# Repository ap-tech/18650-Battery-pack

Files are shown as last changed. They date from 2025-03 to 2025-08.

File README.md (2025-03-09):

# 18650-Battery-pack
This is a repository for making 18650 Battery packs. I will be making 3cell, 4cell, and 6cell. All packs will have inbuilt battery balancer from AliExpress I will also be looking at charging with just an off the shelf 24v power supply or transformer. The reason for this is so that you don't need to use "hard to come by" hobby modle chargers

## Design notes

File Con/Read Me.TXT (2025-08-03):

README: Handheld Device Schematic (KiCad)
Overview

This repository contains the KiCad schematic for a versatile handheld device. The design focuses on providing a robust foundation for custom projects, integrating a microcontroller with a power management solution that supports charging from a 24V transformer. This schematic is intended to be a starting point for hobbyists, students, and engineers looking to quickly prototype and build their own portable electronic devices.
Features

 Microcontroller Integration: Designed to easily accommodate a SAMD21 microcontroller with necessary power and peripheral connections.

3-Cell 18650 Battery Support: Includes provisions for a 3-cell 18650 battery pack, providing portable power for the device.

24V Charging Capability: Includes a power management circuit capable of safely stepping down and regulating a 24V DC input for charging the 3-cell 18650 battery pack and powering the device operation.

Modular Design: The schematic is organized into logical blocks, making it easy to understand, modify, and adapt for various applications.

KiCad Format: Provided in KiCad's native format, ensuring full compatibility for editing, simulation, and PCB layout generation.

How to Use This Schematic

To utilize this schematic for your own projects, follow these steps:

Review and Understand: Familiarize yourself with the different sections of the schematic, including the microcontroller section, power management, and any peripheral interfaces.

Customize:

Microcontroller: Adapt the pin assignments and peripheral connections to match your SAMD21 microcontroller.

Peripherals: Add or remove components for specific sensors, displays, communication modules, or other functionalities your handheld device requires.

Create PCB Layout: Once you are satisfied with the schematic, use KiCad's PCB editor to design your custom printed circuit board based on this schematic. Ensure proper component footprints and routing for optimal performance.

Important Considerations

Component Selection: While the schematic provides placeholders, ensure you select appropriate components with the correct voltage ratings, current capabilities, and package types for your application, especially those related to the 24V input and 3-cell 18650 battery pack.

Battery Management: The 24V charging circuit is designed for basic power input to charge a 3-cell 18650 battery pack. For proper and safe charging of Li-Ion batteries like 18650s, it is crucial to integrate a dedicated Battery Management System (BMS) IC. This BMS should handle aspects like cell balancing, over-charge protection, over-discharge protection, and over-current protection to ensure battery longevity and safety. The schematic provides the power path, but a comprehensive BMS is highly recommended for the battery pack.

Safety: Always exercise caution when working with electrical circuits, especially those involving higher voltages and Li-Ion batteries. Double-check your connections and component ratings. Improper handling of Li-Ion batteries can be dangerous.

Testing: Thoroughly test your assembled board, starting with power supply checks, before connecting sensitive components or full functionality.

Contributing

Feel free to fork this repository, make improvements, or suggest changes. Your contributions are welcome!
License

This project is open-source and released under the MIT License.

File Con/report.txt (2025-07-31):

Info: Total warnings: 0, errors: 0.
Info: Processing symbol 'U1:Package_QFP:TQFP-48_7x7mm_P0.5mm'.
Added U1 (footprint 'Package_QFP:TQFP-48_7x7mm_P0.5mm').
Changed REF** reference designator to U1.
Changed U1 value from TQFP-48_7x7mm_P0.5mm to ATSAMD21G15B-A.
Updated U1 symbol association from  to /875e85b6-29ea-47d7-8ef3-6b790c67f0cd.
Updated U1 fields.
Updated U1 sheetname to '/'.
Updated U1 sheetfile to 'Con.kicad_sch'.
Updated U1 footprint filters to 'TQFP*7x7mm*P0.5mm*'.
Add net unconnected-(U1-PA30-Pad45).
Connected U1 pin 45 to unconnected-(U1-PA30-Pad45).
Add net unconnected-(U1-PA13-Pad22).
Connected U1 pin 22 to unconnected-(U1-PA13-Pad22).
Add net unconnected-(U1-PA08-Pad13).
Connected U1 pin 13 to unconnected-(U1-PA08-Pad13).
Add net unconnected-(U1-PB10-Pad19).
Connected U1 pin 19 to unconnected-(U1-PB10-Pad19).
Add net unconnected-(U1-PA19-Pad28).
Connected U1 pin 28 to unconnected-(U1-PA19-Pad28).
Add net unconnected-(U1-VDDANA-Pad6).
Connected U1 pin 6 to unconnected-(U1-VDDANA-Pad6).
Add net unconnected-(U1-PA23-Pad32).
Connected U1 pin 32 to unconnected-(U1-PA23-Pad32).
Add net unconnected-(U1-PA12-Pad21).
Connected U1 pin 21 to unconnected-(U1-PA12-Pad21).
Add net unconnected-(U1-PA22-Pad31).
Connected U1 pin 31 to unconnected-(U1-PA22-Pad31).
Add net unconnected-(U1-VDDIO-Pad17).
Connected U1 pin 17 to unconnected-(U1-VDDIO-Pad17).
Add net Net-(U1-GND-Pad18).
Connected U1 pin 18 to Net-(U1-GND-Pad18).
Add net unconnected-(U1-PB22-Pad37).
Connected U1 pin 37 to unconnected-(U1-PB22-Pad37).
Add net unconnected-(U1-PA15-Pad24).
Connected U1 pin 24 to unconnected-(U1-PA15-Pad24).
Add net unconnected-(U1-PA21-Pad30).
Connected U1 pin 30 to unconnected-(U1-PA21-Pad30).
Add net unconnected-(U1-PB02-Pad47).
Connected U1 pin 47 to unconnected-(U1-PB02-Pad47).
Add net unconnected-(U1-PA09-Pad14).
Connected U1 pin 14 to unconnected-(U1-PA09-Pad14).
Add net unconnected-(U1-PA28-Pad41).
Connected U1 pin 41 to unconnected-(U1-PA28-Pad41).
Add net unconnected-(U1-PA10-Pad15).
Connected U1 pin 15 to unconnected-(U1-PA10-Pad15).
Add net unconnected-(U1-PA31-Pad46).
Connected U1 pin 46 to unconnected-(U1-PA31-Pad46).
Add net unconnected-(U1-PA24-Pad33).
Connected U1 pin 33 to unconnected-(U1-PA24-Pad33).
Add net unconnected-(U1-PB23-Pad38).
Connected U1 pin 38 to unconnected-(U1-PB23-Pad38).
Add net unconnected-(U1-PA04-Pad9).
Connected U1 pin 9 to unconnected-(U1-PA04-Pad9).
Connected U1 pin 7 to unconnected-(U1-PB08-Pad7).
Add net unconnected-(U1-PA03-Pad4).
Connected U1 pin 4 to unconnected-(U1-PA03-Pad4).
Connected U1 pin 42 to Net-(U1-GND-Pad18).
Add net unconnected-(U1-PA17-Pad26).
Connected U1 pin 26 to unconnected-(U1-PA17-Pad26).
Add net unconnected-(U1-PB11-Pad20).
Connected U1 pin 20 to unconnected-(U1-PB11-Pad20).
Add net unconnected-(U1-VDDIO-Pad36).
Connected U1 pin 36 to unconnected-(U1-VDDIO-Pad36).
Add net unconnected-(U1-PA27-Pad39).
Connected U1 pin 39 to unconnected-(U1-PA27-Pad39).
Add net unconnected-(U1-GNDANA-Pad5).
Connected U1 pin 5 to unconnected-(U1-GNDANA-Pad5).
Connected U1 pin 35 to Net-(U1-GND-Pad18).
Add net unconnected-(U1-PA02-Pad3).
Connected U1 pin 3 to unconnected-(U1-PA02-Pad3).
Add net unconnected-(U1-PA11-Pad16).
Connected U1 pin 16 to unconnected-(U1-PA11-Pad16).
Add net unconnected-(U1-~{RESET}-Pad40).
Connected U1 pin 40 to unconnected-(U1-~{RESET}-Pad40).
Add net unconnected-(U1-PA00-Pad1).
Connected U1 pin 1 to unconnected-(U1-PA00-Pad1).
Add net unconnected-(U1-PB03-Pad48).
Connected U1 pin 48 to unconnected-(U1-PB03-Pad48).
Add net unconnected-(U1-VDDCORE-Pad43).
Connected U1 pin 43 to unconnected-(U1-VDDCORE-Pad43).
Add net unconnected-(U1-PA25-Pad34).
Connected U1 pin 34 to unconnected-(U1-PA25-Pad34).
Add net unconnected-(U1-PA05-Pad10).
Connected U1 pin 10 to unconnected-(U1-PA05-Pad10).
Add net unconnected-(U1-PA06-Pad11).
Connected U1 pin 11 to unconnected-(U1-PA06-Pad11).
Add net unconnected-(U1-VDDIN-Pad44).
Connected U1 pin 44 to unconnected-(U1-VDDIN-Pad44).
Add net unconnected-(U1-PB09-Pad8).
Connected U1 pin 8 to unconnected-(U1-PB09-Pad8).
Add net unconnected-(U1-PA14-Pad23).
Connected U1 pin 23 to unconnected-(U1-PA14-Pad23).
Add net unconnected-(U1-PA18-Pad27).
Connected U1 pin 27 to unconnected-(U1-PA18-Pad27).
Add net unconnected-(U1-PA07-Pad12).
Connected U1 pin 12 to unconnected-(U1-PA07-Pad12).
Add net unconnected-(U1-PA16-Pad25).
Connected U1 pin 25 to unconnected-(U1-PA16-Pad25).
Add net unconnected-(U1-PA01-Pad2).
Connected U1 pin 2 to unconnected-(U1-PA01-Pad2).
Add net unconnected-(U1-PA20-Pad29).
Connected U1 pin 29 to unconnected-(U1-PA20-Pad29).

Add net unconnected-(U1-PB08-Pad7).

Info: Total warnings: 0, errors: 0.

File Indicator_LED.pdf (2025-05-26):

# Indicator RGB LED

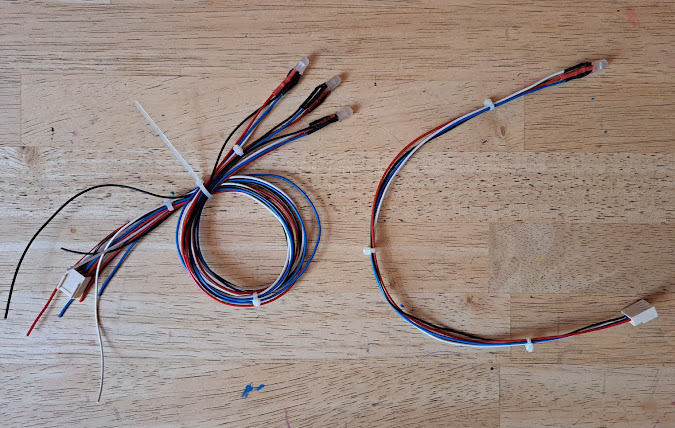
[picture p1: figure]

Indicator LEDs mainly to show battery power level on my robots. Originally I was thinking about using them on my remote controllers as well but then decided to use OLED displays for that. The heart and soul of the indicator is the WS2812 5mm LED. preferably the diffused or milky type. I don’t like the clear type since you can see the individual LEDs in the package instead of just the single output colour. On the other side of the wire harness is a 4 pin female 2510-AW-2.5 connector. In some of them (as can be seen in the left of the pic) I did not attach a connector incase there was to much wire for the application. in that case you just cut the length of wire that you need and then attach the connector. integrated in the assembly is a 470 ohm resistor it’s covered with a red heat shrink and is on the VDD or the power pin. The input power for this device is 5 voltes and the data sheet says to put a 100 ohm resistor on the power pin but I chose a 470 ohm one. I think having the power resistor integrated like this will save board space on the charging board. I don’t know the wire’s gauge but it is the thinest wire I could get from my local supplier. The colours used are red, Blue, White, and Black. also I used the smallest cable ties I have to keep everything together as can be seen on the right in the pic.

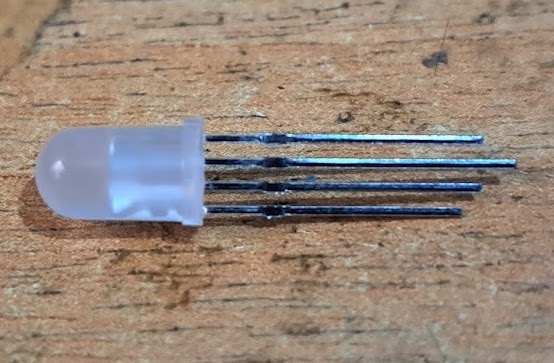
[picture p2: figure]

This is the WS2812 5mm LED. I got a hundred of them from AliExpress for very cheap.

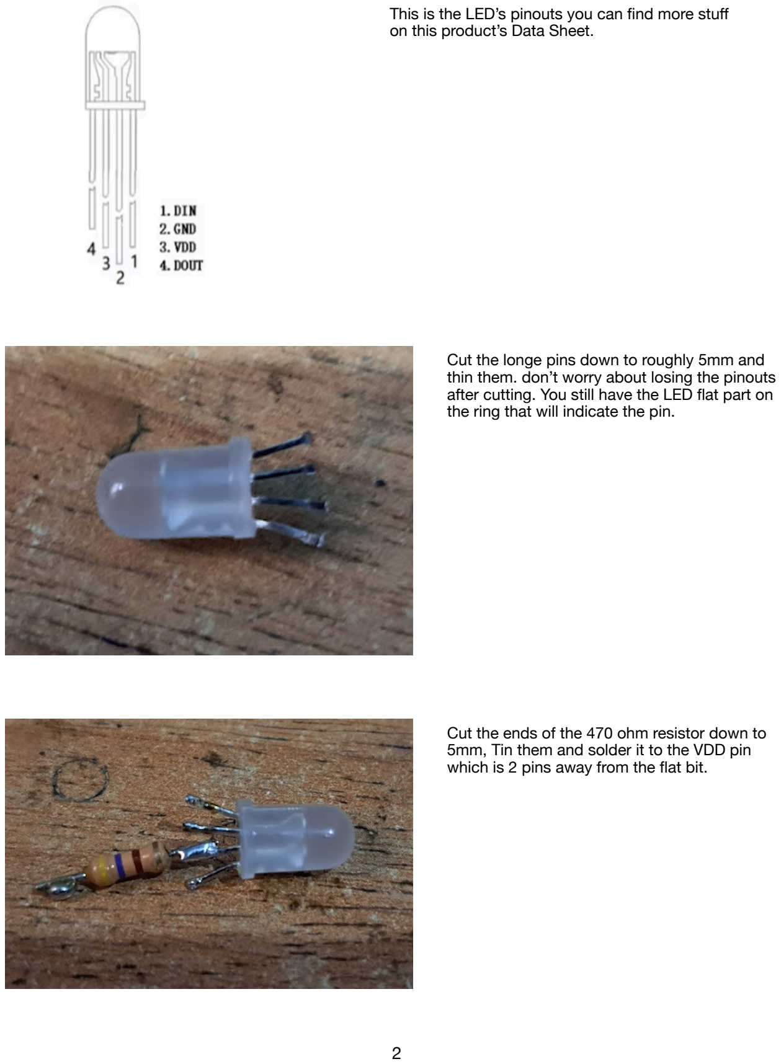
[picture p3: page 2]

This is the LED’s pinouts you can find more stuff on this product’s Data Sheet.

Cut the longe pins down to roughly 5mm and thin them. don’t worry about losing the pinouts after cutting. You still have the LED flat part on the ring that will indicate the pin.

Cut the ends of the 470 ohm resistor down to 5mm, Tin them and solder it to the VDD pin which is 2 pins away from the flat bit.

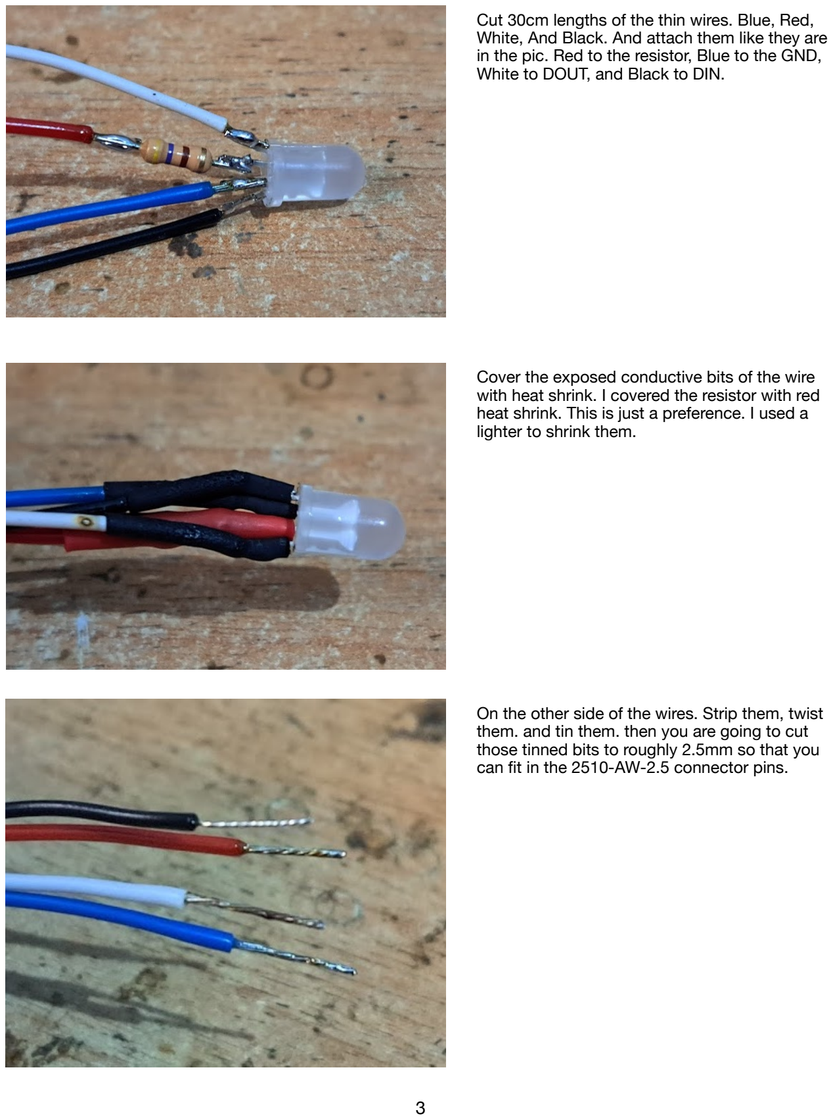
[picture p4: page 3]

Cut 30cm lengths of the thin wires. Blue, Red, White, And Black. And attach them like they are in the pic. Red to the resistor, Blue to the GND, White to DOUT, and Black to DIN.

Cover the exposed conductive bits of the wire with heat shrink. I covered the resistor with red heat shrink. This is just a preference. I used a lighter to shrink them.

On the other side of the wires. Strip them, twist them. and tin them. then you are going to cut those tinned bits to roughly 2.5mm so that you can fit in the 2510-AW-2.5 connector pins.

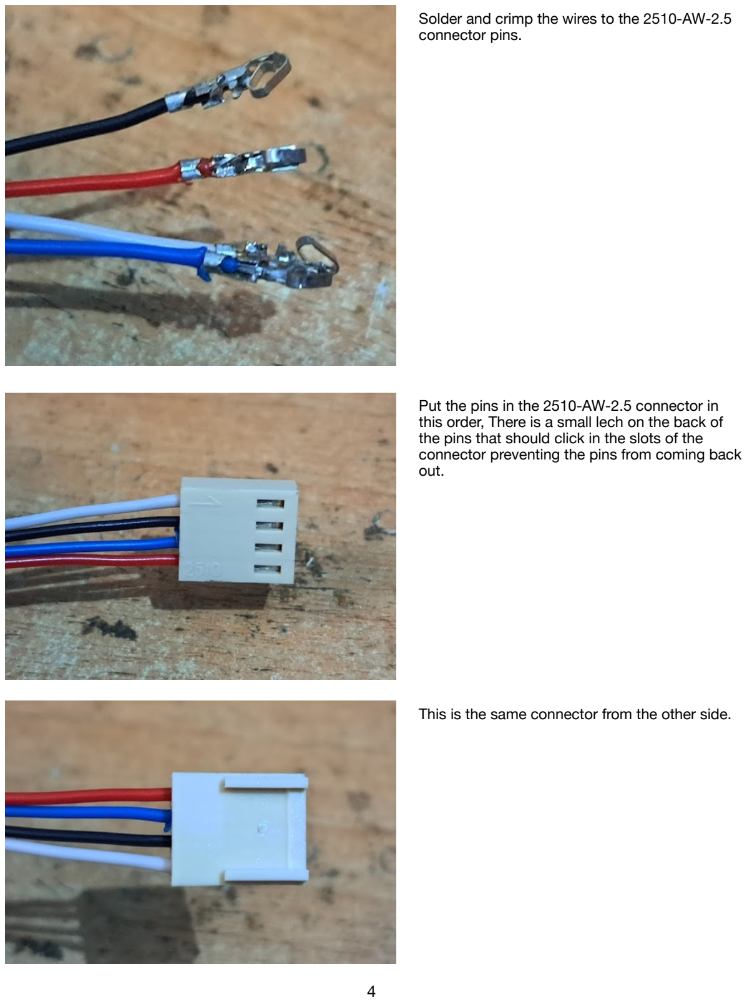
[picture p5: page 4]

Solder and crimp the wires to the 2510-AW-2.5 connector pins.

Put the pins in the 2510-AW-2.5 connector in this order, There is a small lech on the back of the pins that should click in the slots of the connector preventing the pins from coming back out.

This is the same connector from the other side.

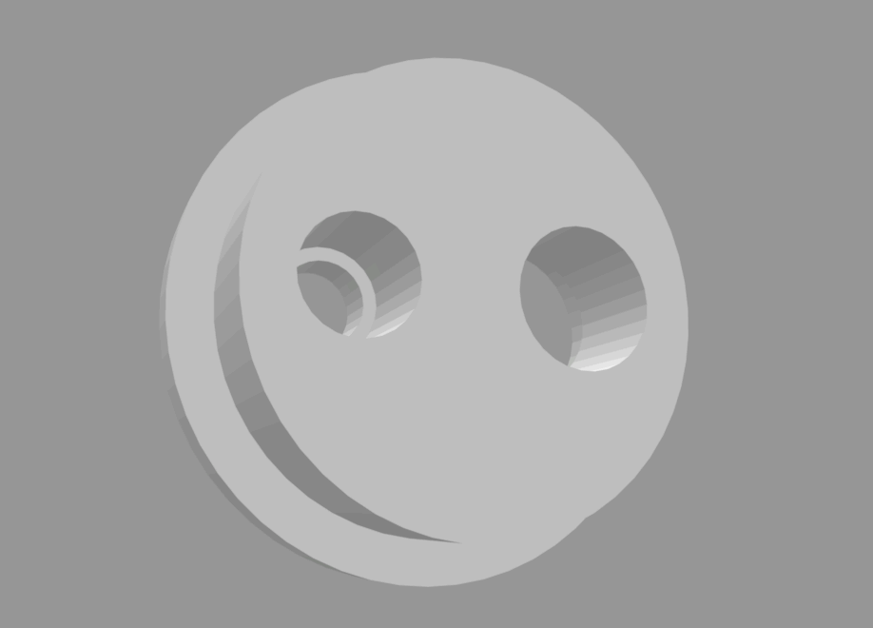
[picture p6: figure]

So the question then is ‘How do you mount these indicators to a panel?’ I glue them I use a hi viscosity super glue or gel like (so that it doesn’t run everywhere) and I just stick it in the smaller hole with the recess. The recess just prevents the indicator from going strait through. I then fill the other side with the viscose super glue. The other hole is for a barrel jack for the charger. The STL files for this part can be found on my GitHub:

https://github.com/ap-tech/18650-Battery-pack/blob/main/Miscellaneous3D%20Prints/24v_DC_Plug.stl

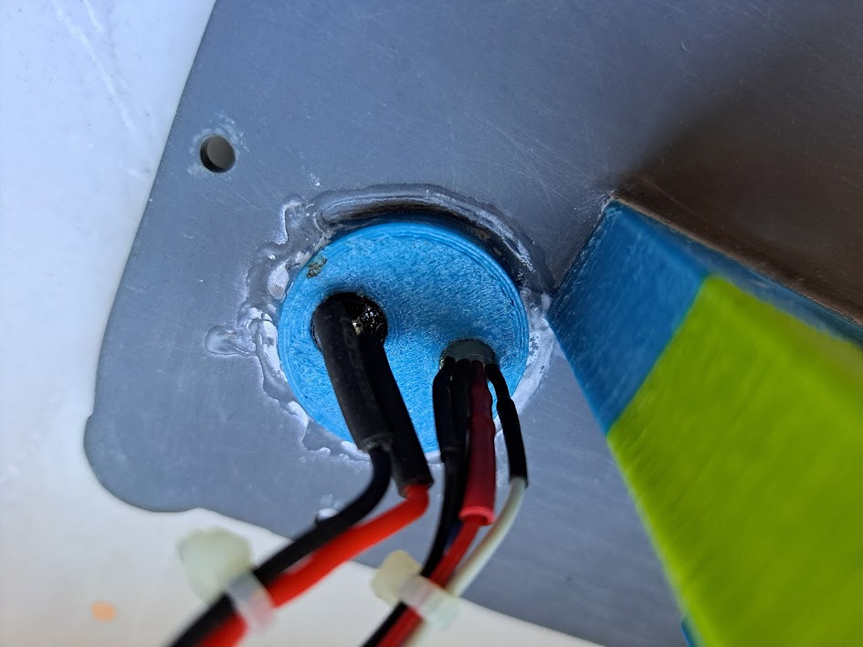
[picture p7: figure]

This is what the part looks like with indicator and barrel jack attached and it being attached to a panel. you can also see the dried super glue around the part. The part was designed so the you can cut a hole in the panel that you are mounting this too with a 28mm or a 17/64” hole saw.

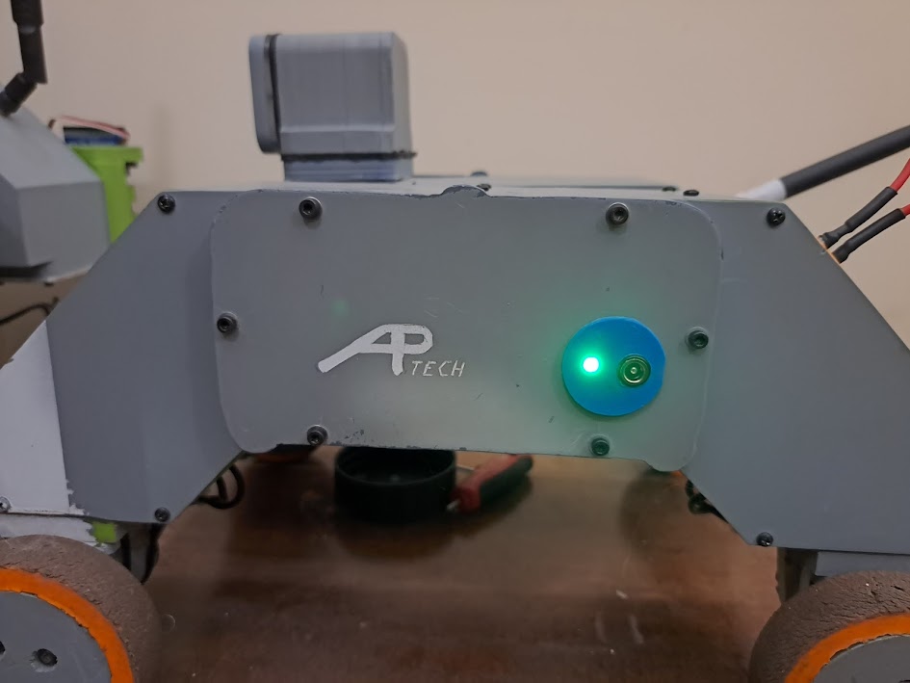
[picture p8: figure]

This is the part from the other side with the indicator in action glowing green meaning the battery is full.

Written By: Anthony Pirotta.
For: AP tech Robots, Hand held devices, And other products. Date: Tuesday, 26 May 2025
Revised:
Notes:
Disclaimer: AP tech and Anthony Pirotta are not responsible for any fires, explosions, damage or death occurring after someone uses these instructions. Making lithium batteries is a risky activity and one that you and only you are responsible for. Also before following these instructions it is best to have prior electrical, electronics, And soldering knowledge and experience.

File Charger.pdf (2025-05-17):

# AP Tech Charger

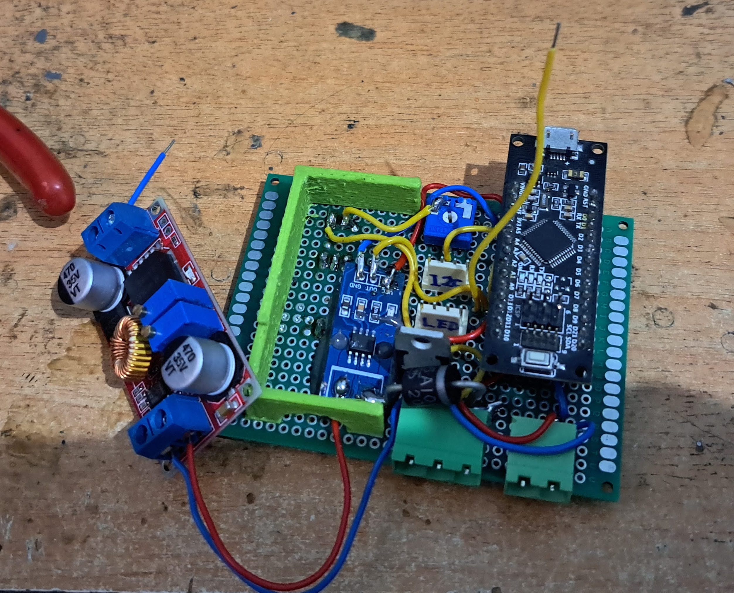
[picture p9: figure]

1

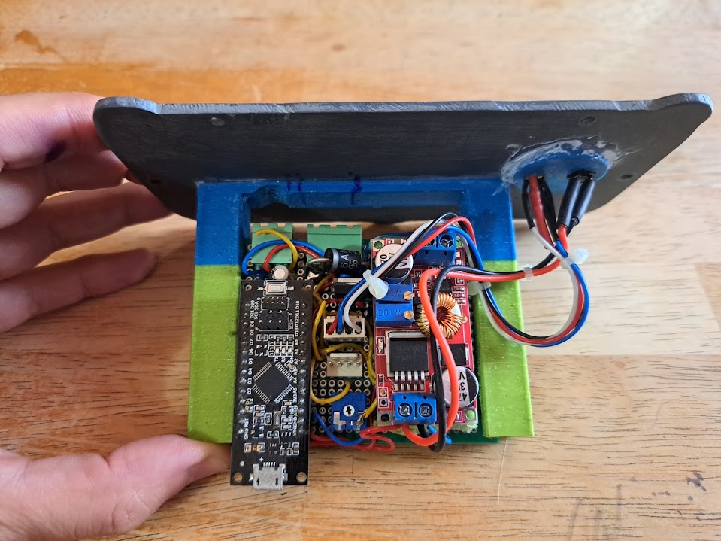
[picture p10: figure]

2

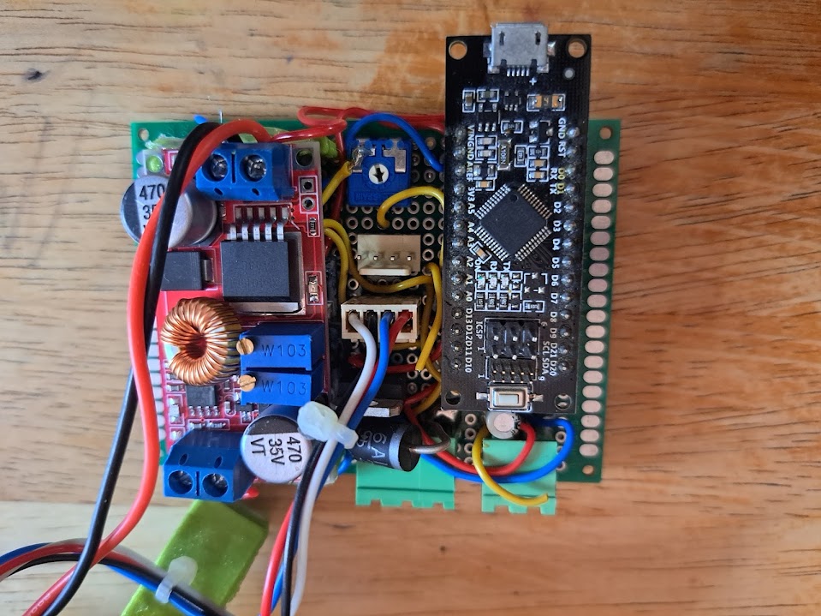
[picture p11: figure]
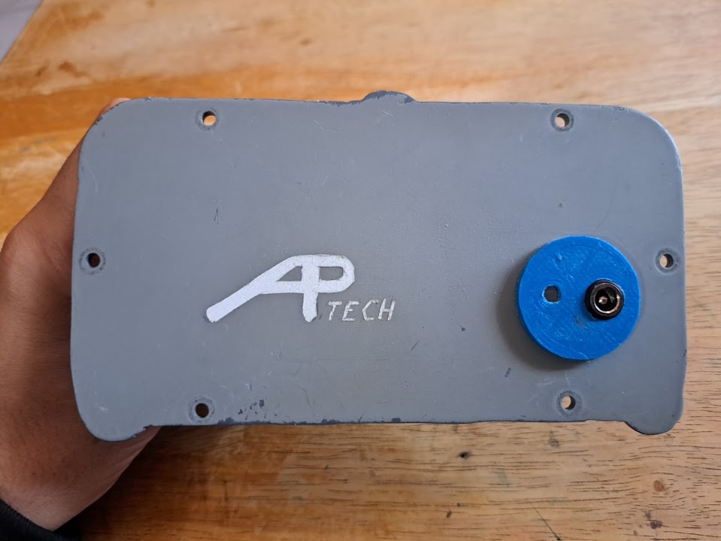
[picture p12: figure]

3 | 4

Here I show how I made a battery management system that can charge my 3 cell battery packs with an of the shelf 24v 5A transformer. the whole thing is built on a 60x80mm prototyping board and the brains of the operation is a SAMD21 based microcontroller board. The heart of the board is the red voltage and current regulating board. this is what drops the voltage coming from the 24v transformer to a voltage the battery pack can take. it is suspended over the board with a green 3D printed part (pic 1) so that I could fit more boards and components underneath. stuff like a current sensor and an optocoupler (which can’t be seen since I attached it from the other side) The 3D printed part was attached to the board using super glue and after the red board was attached the to it using hot glue. The idea being that if I need to remove it for some reason the hot glue would be easer to remove. The SAMD21 chip reads the analog battery voltage through the optocoupler and a voltage divider when the device is in use. And reads the current through the current sensor when it is being charged. It displays the status of the battery through an RGB LED on the blue round panel in pic 4. This panel also has the charging jack. In the future I would like to communicate the battery state to the robot’s RP2040 chip via I2C from the board. That is why there is an unoccupied 4 pin molex connector in the middle of the board. This is not the final iteration of the board. Eventually I will make a cleaner one with a custom printed circuit board from a service like PCBWay or JLCPCB.

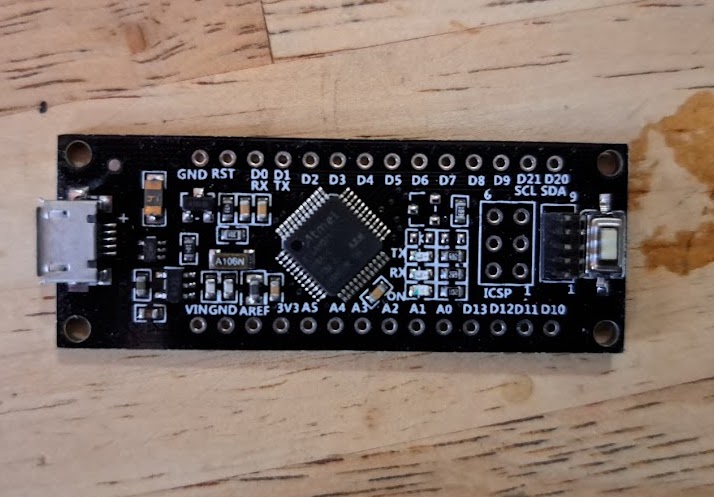
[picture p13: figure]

SAMD21 Breakout board. I use a WeMos one from AliExpress and I program it using the Arduino IDE. The board has analog the digital converters of which I'm using two. One for reading the battery voltage, And the other for reading the charge current from the current sensor. It also has an I2C bus which I will use to communicate with the main processor on my robot so that it can know stuff like battery level.

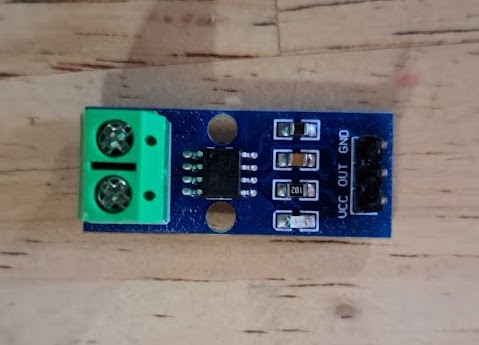
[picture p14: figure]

5A Current Sensor Module ACS712. It is important that it is the 5 amp type. AliExpress gives you a choice. 5A, 20A, and so on. originally I thought that this value meant that the chip can take 5 amps so I went for a bigger number 20 amps thinking that “the bigger the better” but no. What this number is is the sensitivity range meaning that if the current that you are measuring is smaller than 20 amps you will have trouble measuring it. Now it doesn’t say on the board that this is the 5A one. but the way you will know is that the number on the chip will end with 05B.
One thing to note about this device is that when the current is 0 the output will be 2.5v. It then goes up from there as you increase the current.

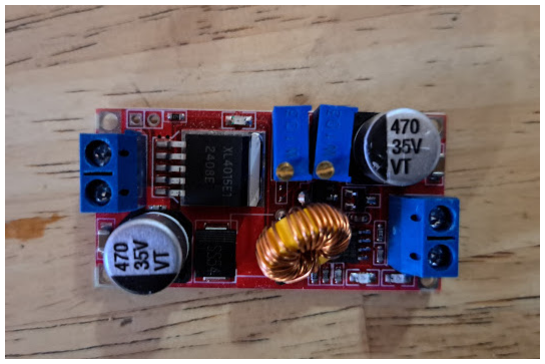
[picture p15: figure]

XL4015 DC to DC Buck Converter. There are different breakout boards for these but I chose these red ones on the count of their smaller size. basically these are voltage and current adjustable power supplies. that is why the two potentiometers. One is for voltage and the other is for current. it is important that they are this type, Voltage and current adjustable. I tried the norma ones where you could only adjust the voltage and they got very hot. Not good. The settings for this project should be 1.5 for the amps and 13 for the voltes.

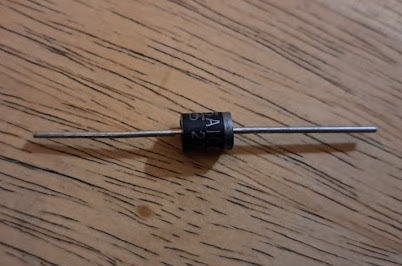
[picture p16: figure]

The biggest diode I could find. I don’t know the rating on it I just know that it is bigger than the normal 2.5mm wide diodes which were getting hot in this application. This diode is 7mm wide. it was still getting a bit warm but I will fix that when I create a custom PCB version of this board.

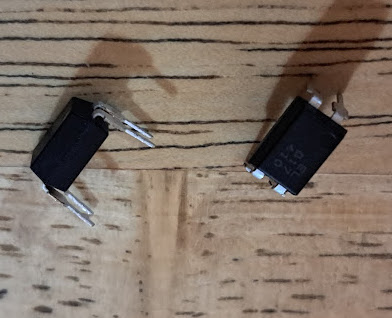
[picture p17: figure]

Optocoupler 817A. I got the ones you see here from a supplier close to where I live and the number is EL817. I will use this optocoupler to switch the voltage divider Off when it is not being used and On again when it is. since voltage dividers are always pulling current making them inefficient. You can also find these on AliExpress.

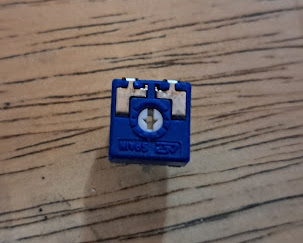
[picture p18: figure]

220K Potentiometer. This will be used to make a voltage divider for the battery voltage sensor.

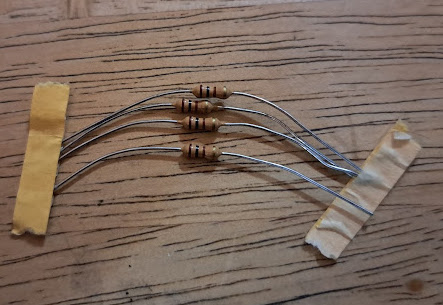
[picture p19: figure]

Quarter watt resistors 1K and 10K. It is always a good thing to have an assortment of Quarter watt resistors.

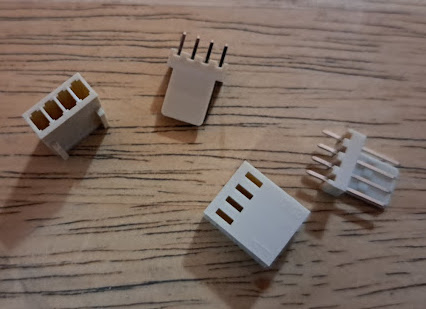
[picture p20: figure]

2510-AW-2.5. 4 pin type. Both the male for soldering to the PCB board and the female (plus the pins that come with them) for making the cable harnesses. In this board I’m using them for the I2C cable and the indicator LED.

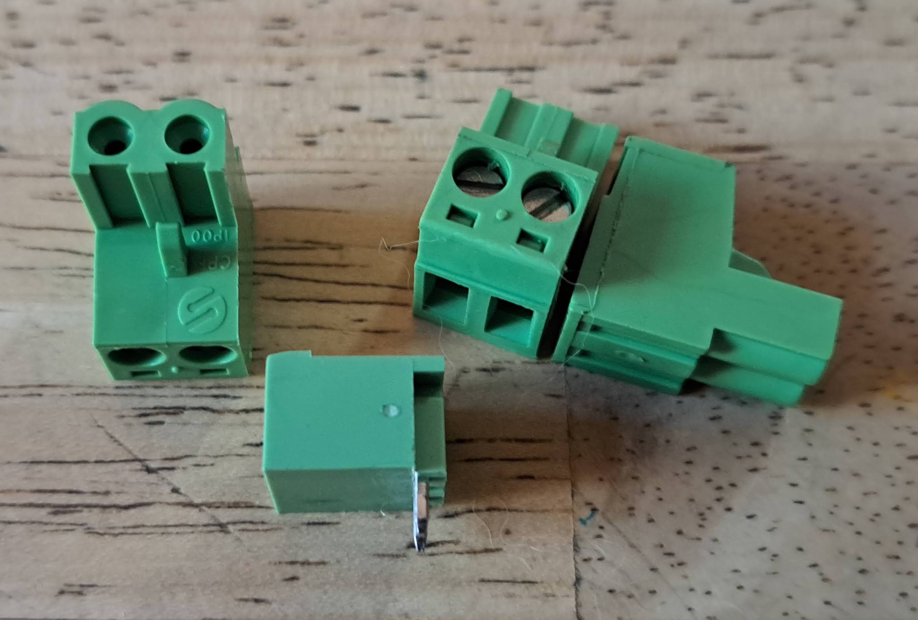
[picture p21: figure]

KF2EDGK-5.08 Connectors. 2 pin and 3pin. these components are made of two parts. A part that solders to the PCB board. and a detachable part that you screw your wires to. I find these connectors great especially for maintenance since you can just detach your wires from the board without having them touch each other. good for safety for when working around lithium battery packs.

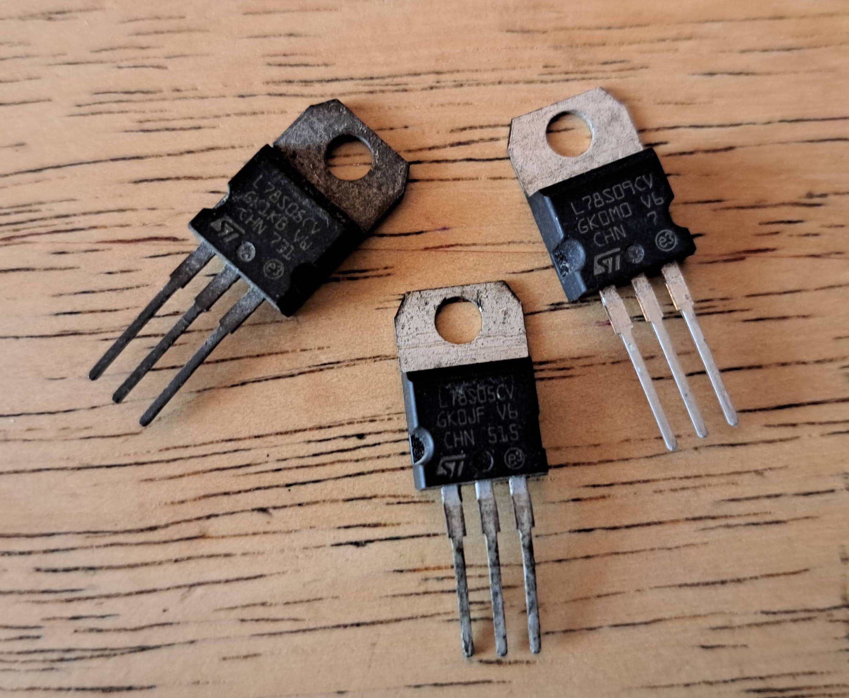
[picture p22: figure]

L7805 5v voltage regulator. Originally I wanted to use a DC to DC converter (more efficient) but because of board space considerations, and the fact that this is a prototype, I went with a voltage regulator. In the custom PCB version I will be using a DC to DC convertor and will be exploring giving power supplies to other boards with 5 volts from the charging board.

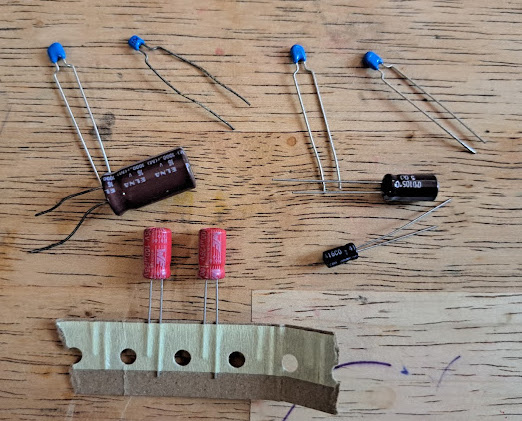
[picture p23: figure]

An assortment of capacitors. important to have. I will not go into details of what I am using in this board since I use them where ever I have to clean an analog signal or filter ripples in a power supply. And that is something that in a circuit like this you must see for yourself what cap you will need. in the custom PCB version I will have more details on capacitors.

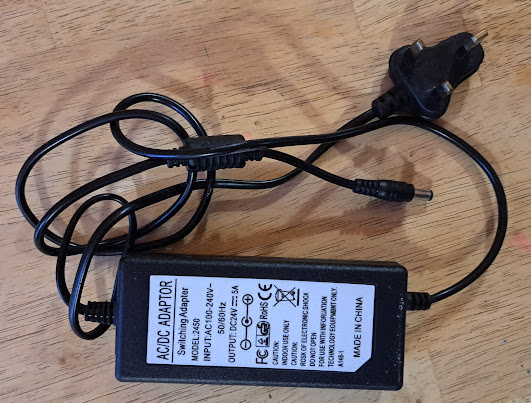
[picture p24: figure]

24v transformer with barrel jack I want all of my present tech to be charged with these transformers. Even the stuff with the 6 cell battery packs when I eventually make them. Even managed to charge my 3 cell powered robots with a 19v laptop charger which is a bonus.


This is the schematic for the charge circuit. let’s first see what the colour codes mean. The blue and orange lollipop like things are commons. The blue is the Ground or negative common and the orange is the 5v+ coming from the voltage regulator. Now the voltage regulator needs a capacitor on the input and on the output probably even near the components that it is supplying. The turquoise coloured rectangles are resistors with their respective values written next to them. The yellow wires are for the analog signals that will be read by the analog read of the microcontroller’s inputs. One from the current sensor and the other from the voltage sensor. The purple wire is a sense wire that lets the microcontroller know when the barrel jack is in. it’s connected to a voltage divider that turns the 24v of the transformer into a 3.3v logic signal for the microcontroller. The bottom white plug is for I2C but i have not used it yet. in the future I will use it to tell the robot the battery voltage and and maybe even supply 5v to all the boards on the robot. The one at the top is a status LED plug to interface with a WS2812 5mm LED. The Soul of the circuit is the XL4015 board. The power that comes out of it goes through the the current sensor and out the the big diode. The diode is there because when I tested the current with a multimeter I found that when you turn the charge off I was getting a small (in milliamperes) current going the other way and draining the battery if say the robot is inactive for weeks or months. The Optocoupler Potentiometer combo are the battery voltage sensor.

Written By: Anthony Pirotta.
For: AP tech Robots, Hand held devices, And other products. Date: Saturday, 17 May 2025
Revised:
Notes:
Disclaimer: AP tech and Anthony Pirotta are not responsible for any fires, explosions, damage or death occurring after someone uses these instructions. Making lithium batteries is a risky activity and one that you and only you are responsible for. Also before following these instructions it is best to have prior electrical, electronics, And soldering knowledge and experience.

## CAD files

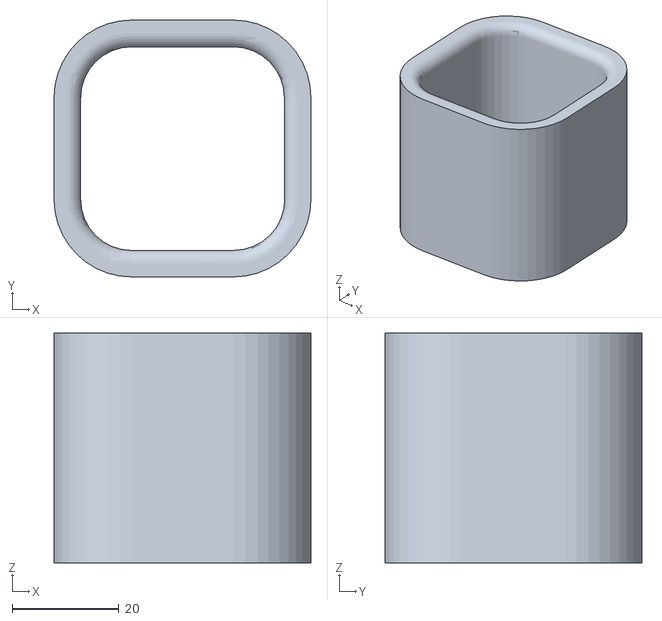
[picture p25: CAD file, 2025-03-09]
Jigs/4_Cell-Body.stl
48.1 x 48.0 x 43.0

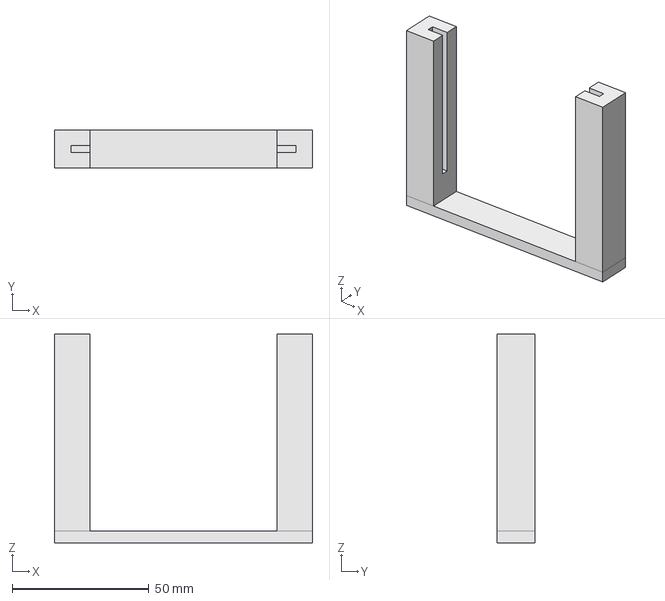
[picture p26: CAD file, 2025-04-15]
Miscellaneous3D Prints/CH_Mount_2.FCStd
94.2 x 14.0 x 76.3 mm

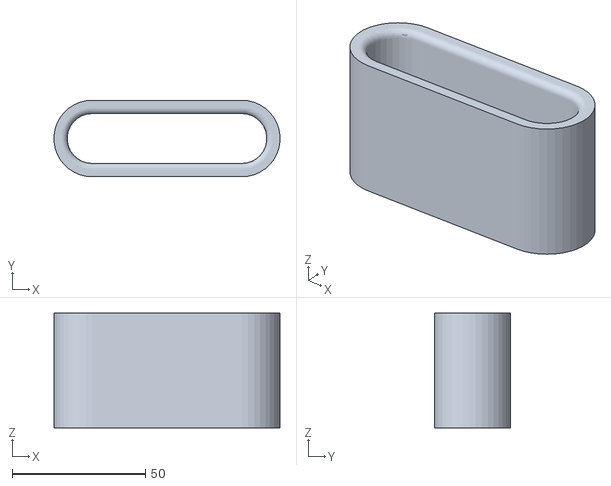
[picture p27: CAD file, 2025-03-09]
Jigs/1865Jig_For_16.8BatteryPack-Body.stl
84.8 x 28.7 x 43.0

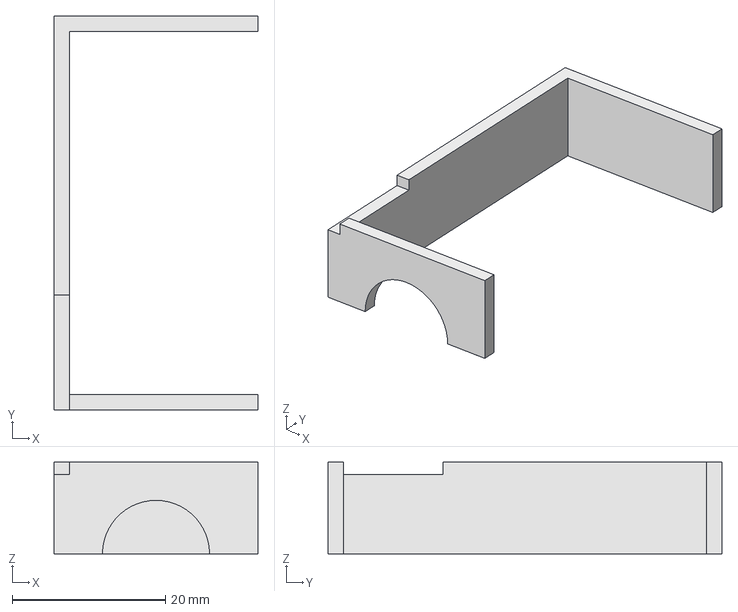
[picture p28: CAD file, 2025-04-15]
Miscellaneous3D Prints/DC_To_DC_Ss.FCStd
26.6 x 51.5 x 12.0 mm

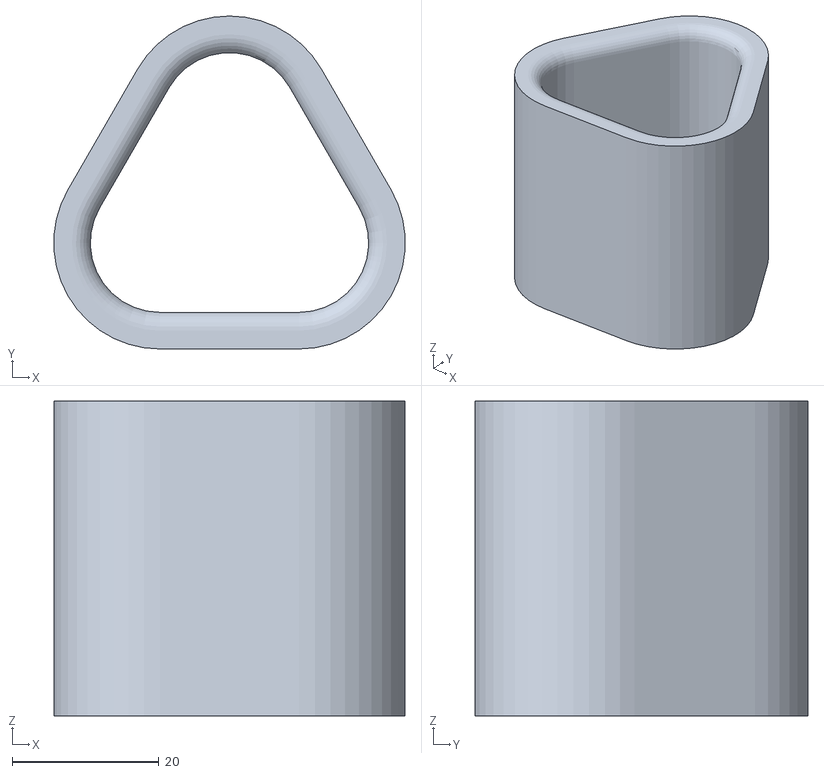
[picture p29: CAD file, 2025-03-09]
Jigs/3_Call_Triangle-Body.stl
47.9 x 45.5 x 43.0

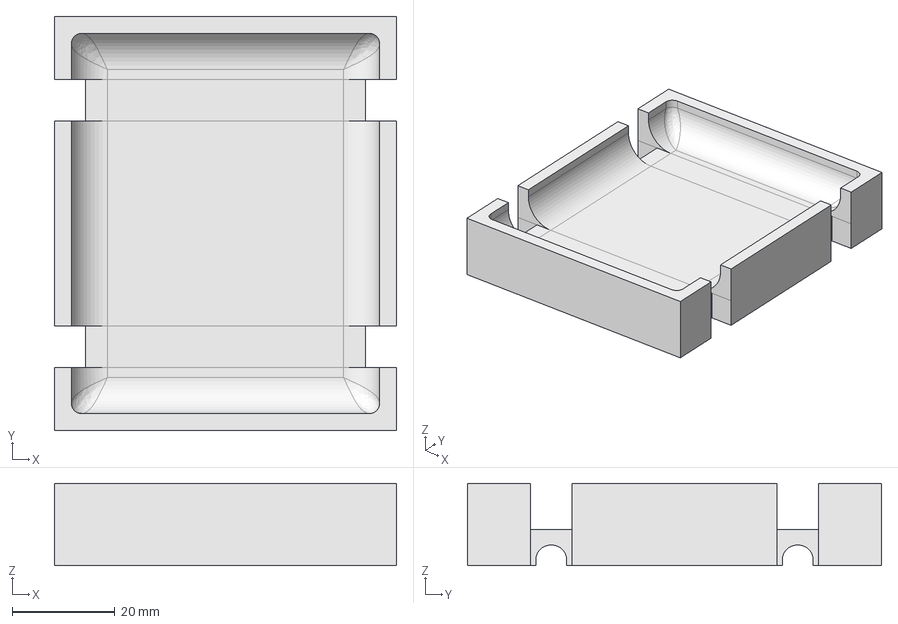
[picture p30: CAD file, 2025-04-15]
Miscellaneous3D Prints/Battery_Pack.FCStd
66.6 x 80.6 x 16.0 mm

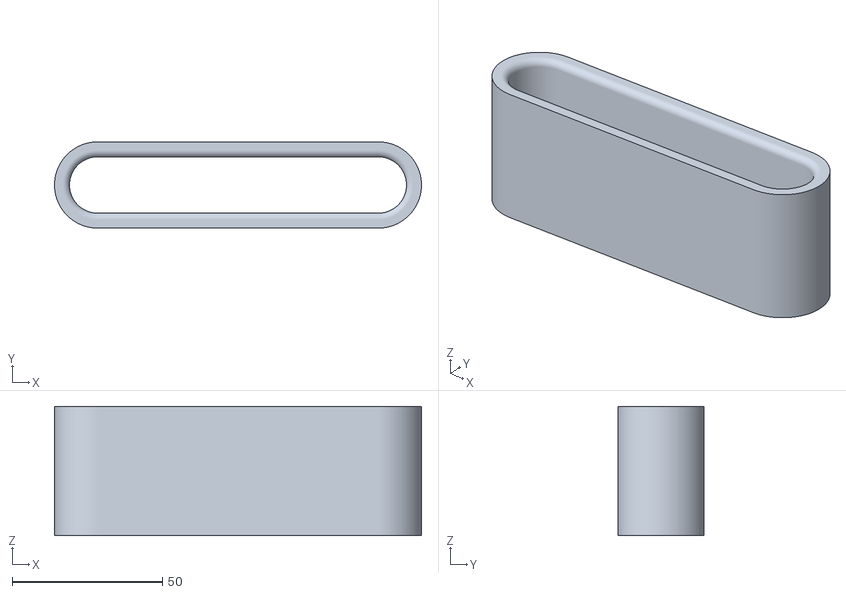
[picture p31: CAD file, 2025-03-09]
Jigs/1865Jig_For_25.2BatteryPack-Body.stl
122.1 x 28.7 x 43.0

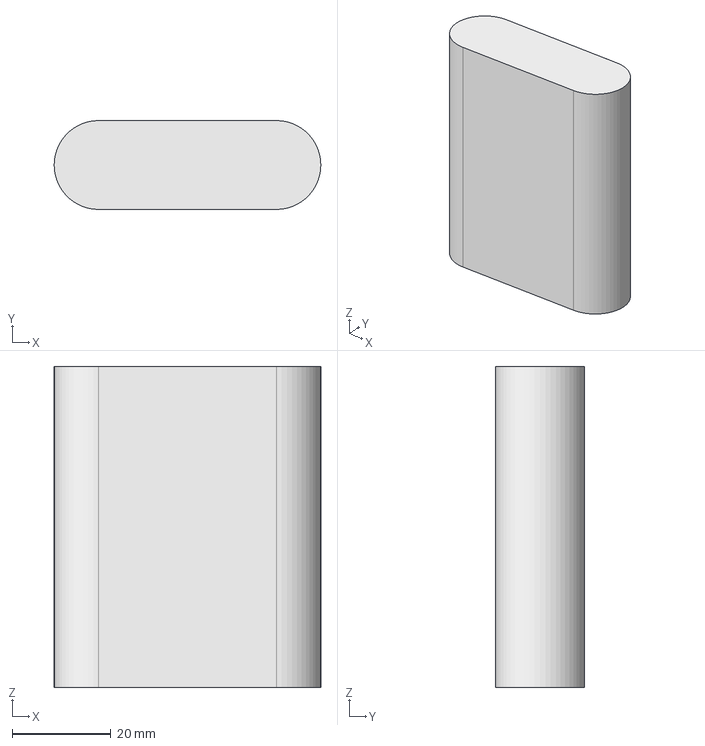
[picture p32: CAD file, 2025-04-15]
Miscellaneous3D Prints/3Cell_Pack_Sim.FCStd
54.0 x 18.0 x 65.0 mm

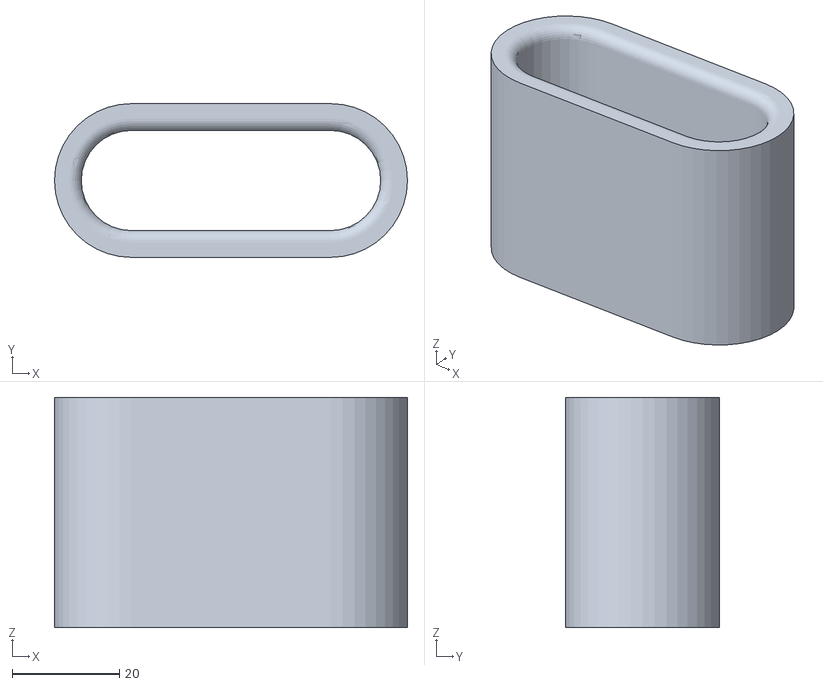
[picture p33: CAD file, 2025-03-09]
Jigs/1865Jig_For_12BatteryPack-Body.stl
65.9 x 28.7 x 43.0

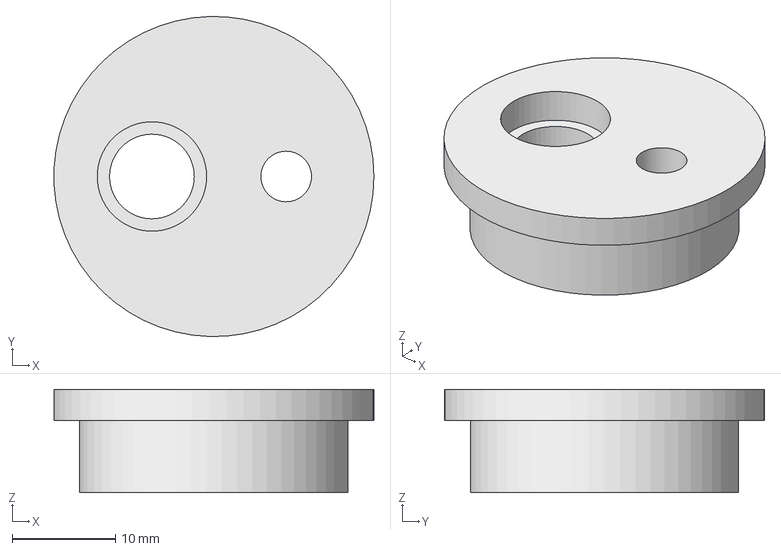
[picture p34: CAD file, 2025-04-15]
Miscellaneous3D Prints/24v_DC_Plug.FCStd
31.0 x 31.0 x 10.0 mm

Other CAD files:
Miscellaneous3D Prints/3Cell_Pack_Sim-B_Pack.stl
Miscellaneous3D Prints/24v_DC_Plug.stl
Miscellaneous3D Prints/Battery_Pack.stl
Miscellaneous3D Prints/CH_Mount_2.stl
Miscellaneous3D Prints/DC_To_DC_Ss.stl

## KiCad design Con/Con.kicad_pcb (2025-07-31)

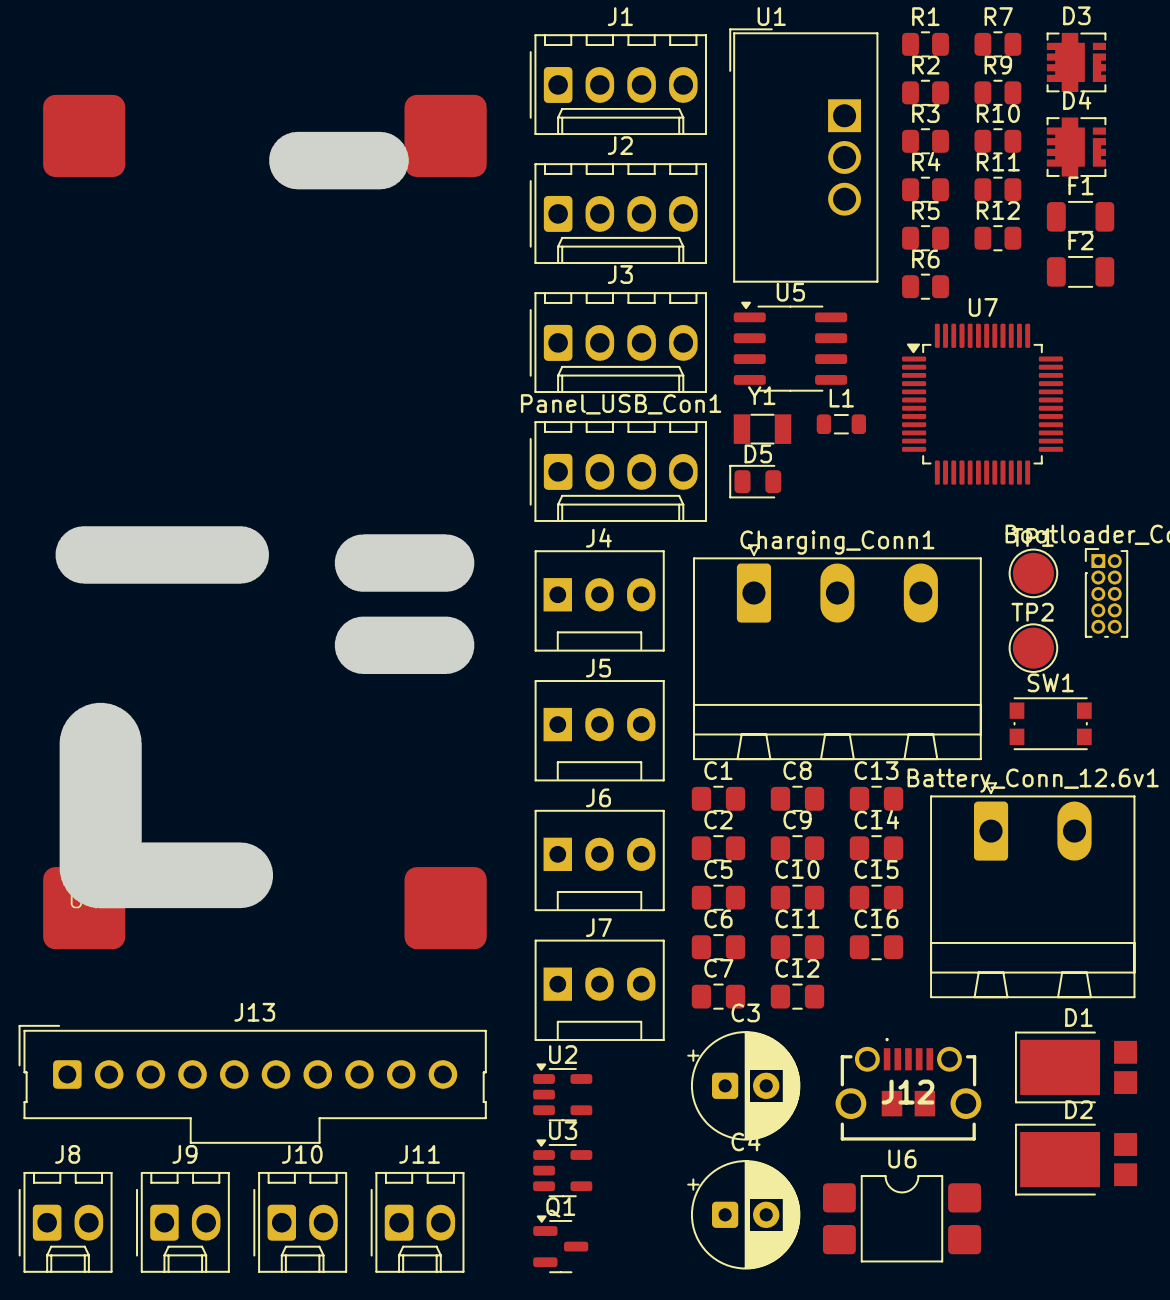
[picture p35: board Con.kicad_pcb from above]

Board: 2 copper layers, 64 parts (0 on the bottom side), 34 nets, no tracks yet.

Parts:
Battery_Conn_12.6v1: Conn_01x02_Pin; PhoenixContact_MSTBA_2,5_2-G-5,08_1x02_P5.08mm_Horizontal
Bootloader_Con1: Conn_02x05_Odd_Even; PinHeader_2x05_P1.00mm_Vertical
C1, C2: 1mF; C_0805_2012Metric_Pad1.18x1.45mm_HandSolder
C3, C4: 220 μF; CP_Radial_D6.3mm_P2.50mm
C5, C6, C7, C8: 22µF; C_0805_2012Metric_Pad1.18x1.45mm_HandSolder
C9: 0.1 μF; C_0805_2012Metric_Pad1.18x1.45mm_HandSolder
C10: 1 nF; C_0805_2012Metric_Pad1.18x1.45mm_HandSolder
C11, C12, C13: 100nF; C_0805_2012Metric_Pad1.18x1.45mm_HandSolder
C14: 1µF; C_0805_2012Metric_Pad1.18x1.45mm_HandSolder
C15, C16: 22pF; C_0805_2012Metric_Pad1.18x1.45mm_HandSolder
Charging_Conn1: Conn_01x03_Pin; PhoenixContact_MSTBA_2,5_3-G-5,08_1x03_P5.08mm_Horizontal
D1, D2: D; D_PowerDI-5
D3, D4: D; D_QFN_3.3x3.3mm_P0.65mm
D5: LED; LED_0805_2012Metric
F1, F2: Polyfuse; C_1206_3216Metric
J1, J2, J3: Conn_01x04; Molex_KK-254_AE-6410-04A_1x04_P2.54mm_Vertical
J4, J5, J6, J7: Conn_01x03; FanPinHeader_1x03_P2.54mm_Vertical
J8, J9, J10, J11: Conn_01x02; Molex_KK-254_AE-6410-02A_1x02_P2.54mm_Vertical
J12: USB_B_Micro; 101181940001LF
J13: Conn_01x10_Socket; Molex_SL_171971-0010_1x10_P2.54mm_Vertical
L1: 10μH; L_0805_2012Metric
Panel_USB_Con1: Conn_01x04; Molex_KK-254_AE-6410-04A_1x04_P2.54mm_Vertical
Q1: 2N7002H; SOT-23
R1, R7: 10k; R_0805_2012Metric
R2, R6, R11, R12: 1k; R_0805_2012Metric
R3: 220k; R_0805_2012Metric
R4: 47k; R_0805_2012Metric
R5: 22k; R_0805_2012Metric
R9, R10: 4.7k; R_0805_2012Metric
SW1: SW_Omron_B3FS; SW_Push_1P1T_NO_CK_KMR2
TP1: +5V_TestPoint; TestPoint_Pad_D2.5mm
TP2: Batt_SensTestPoint; TestPoint_Pad_D2.5mm
U1: TSR3-2450N; Converter_DCDC_TRACO_TSR2-24xxN_TSR2-24xxxN_THT
U2, U3: AP2112K-3.3; SOT-23-5
U4: DC_DC_Mod
U5: ACS712xLCTR-05B; SOIC-8_3.9x4.9mm_P1.27mm
U6: VO615A-1; SMDIP-4_W7.62mm
U7: ATSAMD21G15B-A; TQFP-48_7x7mm_P0.5mm
Y1: Crystal; Crystal_SMD_3215-2Pin_3.2x1.5mm

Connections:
3.3V_D: C5.1, C7.1, U2.5 (VOUT)
3.3V_M: Bootloader_Con1.1, C6.1, C8.1, C11.2, C12.2, D5.2 (A), L1.1, R7.1, R9.1, R10.1, U3.5 (VOUT), U7.17 (VDDIO), U7.36 (VDDIO), U7.44 (VDDIN)
13V: U4.2 (V_Out), U5.1 (IP+), U5.2 (IP+)
+5V: C1.1, C2.1, C3.1, C4.1, C9.2, F1.2, F2.2, TP1.1, U1.3 (Vout), U2.1 (VIN), U2.3 (EN), U3.1 (VIN), U3.3 (EN), U5.8 (VCC)
+24V: R1.1, U4.4 (V_In)
+BATT Charge: Charging_Conn1.3, D1.1 (K), D2.1 (K)
A0: R3.2, R4.1, TP2.1, U7.3 (PA02)
A1: U5.7 (VIOUT), U7.7 (PB08)
GND: Battery_Conn_12.6v1.2, Bootloader_Con1.3, Bootloader_Con1.5, Bootloader_Con1.9, C1.2, C2.2, C3.2, C4.2, C5.2, C6.2, C7.2, C8.2, C9.1, C10.2, C11.1, C12.1, C13.2, C14.1, C15.2, C16.2, Charging_Conn1.1, J12.5 (GND), Panel_USB_Con1.1, Q1.2 (S), R2.2, R5.2, R11.2, SW1.1, U1.2 (GND), U2.2 (GND), U3.2 (GND), U4.1 (GND), U4.3 (GND), U5.5 (GND), U6.2, U7.5 (GNDANA), U7.18 (GND), U7.35 (GND), U7.42 (GND)
LED_PIN13: Q1.1 (G), R11.1, U7.26 (PA17)
unnamed: Battery_Conn_12.6v1.1, U1.1 (Vin)
unnamed: Charging_Conn1.2, U6.3
unnamed: D1.2 (A), D2.2 (A), U5.3 (IP-), U5.4 (IP-)
unnamed: D5.1 (K), R12.2
unnamed: F2.1, J12.1 (VBUS)
unnamed: F1.1, Panel_USB_Con1.4
unnamed: Q1.3 (D), R12.1
unnamed: R3.1, U6.4
unnamed: R4.2, R5.1
unnamed: R6.2, U6.1
unnamed: C10.1, U5.6 (FILTER)
unnamed: C13.1, L1.2, U7.6 (VDDANA)
unnamed: C14.2, U7.43 (VDDCORE)
OSC1: C15.1, U7.1 (PA00), Y1.1
OSC2: C16.1, U7.2 (PA01), Y1.2
PIN0: R1.2, R2.1, U7.16 (PA11)
PIN1: R6.1, U7.15 (PA10)
Reset: Bootloader_Con1.10, R7.2, SW1.2, U7.40 (~RESET)
SCL: R9.2, U7.32 (PA23)
SDA: R10.2, U7.31 (PA22)
SWCLK: Bootloader_Con1.4, U7.45 (PA30)
SWDIO: Bootloader_Con1.2, U7.46 (PA31)
USB1: J12.2 (D-), Panel_USB_Con1.2, U7.33 (PA24)
USB2: J12.3 (D+), Panel_USB_Con1.3, U7.34 (PA25)

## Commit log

2025-03-09 Add files via upload
    18650 Battery Pack jigs for 3cell 4cell and 6cell.
    [1865Jig_For_12BatteryPack-Body.stl, 1865Jig_For_16.8BatteryPack-Body.stl, 1865Jig_For_25.2BatteryPack-Body.stl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]
2025-07-31 Create Charger_PCB
